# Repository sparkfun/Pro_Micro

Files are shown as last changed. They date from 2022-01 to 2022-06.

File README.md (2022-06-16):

SparkFun Pro Micro and Qwiic Pro Micro USB-C
========================================

<table class="table table-hover table-striped table-bordered">
  <tr>
   <td><a href="https://www.sparkfun.com/products/12587"><div align="center">Pro Micro - 3.3V/8MHz</div></a></td>
   <td><a href="https://www.sparkfun.com/products/12640">Pro Micro - 5V/16MHz</div></a></center></td>
  </tr>
  <tr>
    <td><div align="center">Pro Micro - 3.3V/8MHz <br />[<a href="https://www.sparkfun.com/products/12587">DEV-12587</a>]</div></td>
    <td><div align="center">Pro Micro - 5V/16MHz <br />[<a href="https://www.sparkfun.com/products/12640">DEV-12640</a>]</div></td>
    <td><div align="center">Qwiic Pro Micro - USB-C (ATmega32U4) <br />[<a href="https://www.sparkfun.com/products/15795">DEV-15795</a>]</div></td>
  </tr>
</table>

The Pro Micro is a microcontroller with an ATMega32U4 IC on board. The USB transceiver is inside the 32U4, adding USB connectivity on-board without external USB interfaces. The Pro Micro comes in both a 3.3V and 5V version. For users using the Qwiic Pro Micro USB-C, the board includes a jumper to select either 5V or 3.3V, reset button, castellated pads, and Qwiic connector. The USB connector and voltage regulator are also different. 

Repository Contents
-------------------
* **/Documentation** - Data sheets (.pdf and .svg)
* **/Firmware** - Arduino example code used in the hookup guide
* **/Hardware** - All Eagle design files (.brd, .sch, .STL)
* **/Production** - Test bed files and production panel files

Documentation
--------------
* **Hookup Guide** 
  * **[Pro Micro & Fio V3](https://learn.sparkfun.com/tutorials/pro-micro--fio-v3-hookup-guide)** - Basic hookup guide for the Pro Micro (ATmega32U4) 3.3V and 5V versions as well as the Fio V3.
  * **[Qwiic Pro Micro USB-C](https://learn.sparkfun.com/tutorials/qwiic-pro-micro-usb-c-atmega32u4-hookup-guide)** - Basic hookup guide for the Qwiic Pro Micro.
* **[SparkFun Arduino Board Addon](https://github.com/sparkfun/Arduino_Boards/)** - Arduino board addon for Qwiic Pro Micro.
* **[SparkFun Graphical Datasheets](https://github.com/sparkfun/Graphical_Datasheets)** - Graphical datasheets for various SparkFun products.
* **[SparkFun Fritzing repo](https://github.com/sparkfun/Fritzing_Parts)** - Fritzing diagrams for SparkFun products.

Product Versions
----------------
* [DEV-15795](https://www.sparkfun.com/products/15795)- 5V/16MHz version with Qwiic connector and USB C
* [DEV-12640](https://www.sparkfun.com/products/12640)- 5V/16MHz version
* [DEV-12587](https://www.sparkfun.com/products/12587)- 3.3V/8MHz version

License Information
-------------------
This product is _**open source**_! 

Please review the LICENSE.md file for license information. 

If you have any questions or concerns on licensing, please contact technical support on our [SparkFun forums](https://forum.sparkfun.com/viewforum.php?f=152).

Distributed as-is; no warranty is given.

- Your friends at SparkFun.

_<COLLABORATION CREDIT>_

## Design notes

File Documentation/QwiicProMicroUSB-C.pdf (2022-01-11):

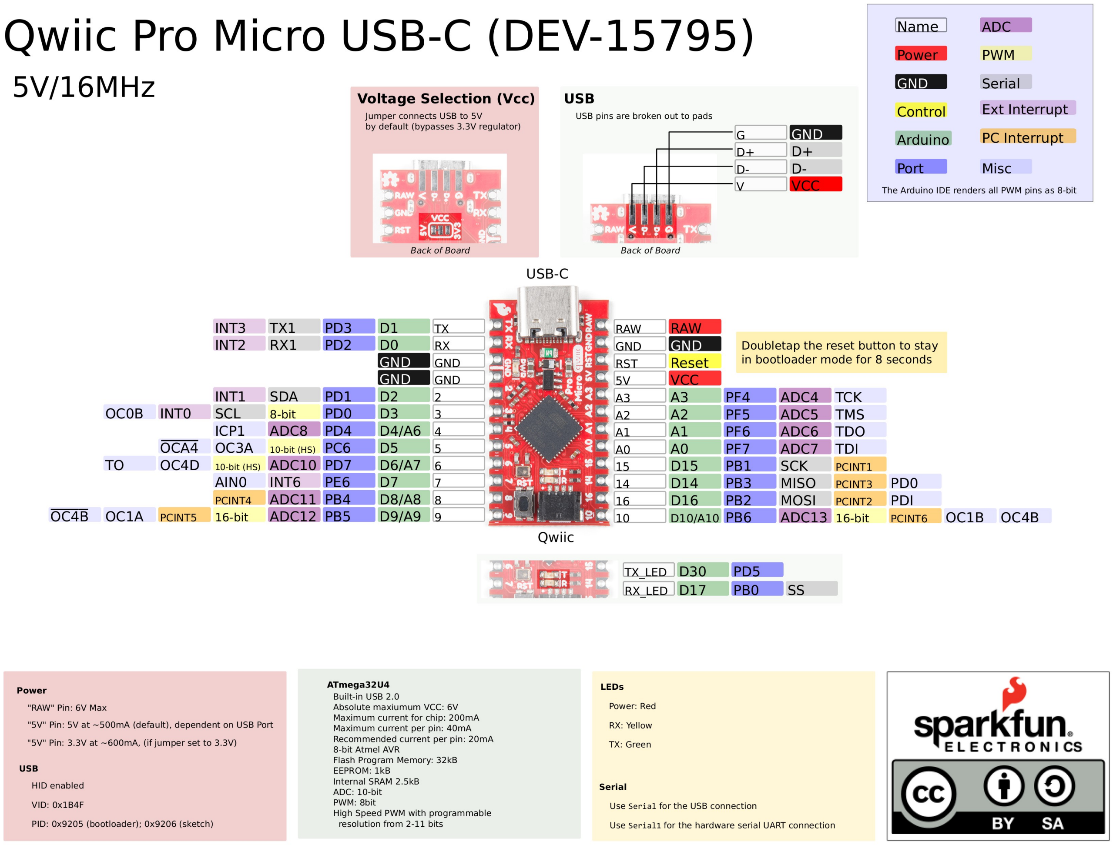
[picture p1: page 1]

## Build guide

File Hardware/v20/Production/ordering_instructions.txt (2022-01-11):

panel size, 133x196mm
PCB thickness, 1.6mm
number of layers, 2
soldermask color, Red
silkscreen color, White
oz copper, 1oz
finish, HASL lead free
stencils, top
pcs per panel, 20
min trace width, 0.152400mm / 0.006000in
min drill size, 0.304800mm / 0.012000in

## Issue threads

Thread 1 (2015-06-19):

Pro Micro v 1.3 schematic has Arduino IDE pin 14 and 17 labels swapped

dmjlambert, 2015-06-19:
Arduino Pin 14 is 32U4 pin 11/MISO and Arduino Pin 17 is 32U4 pin 8/SS which is connected to the RXLED

BrentWilkins, 2015-06-19:
Fixed.  We were using an old version of the ATmega32U4 part.  Thanks!

dmjlambert, 2015-06-20:
I'm sorry Brent, I was not clear and I should have given you more details.   I'm afraid the changes you made were not what I was talking about, could you please revert it back and make different changes?
 Could you please have a look at this attached picture?
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

BrentWilkins, 2015-06-20:
No, you were plenty clear to me.  I fixed it in the v13.1_3.3V branch.  I did so by using current library parts which caused copper to be negligibly altered.  Can't release that until it's proto'd since it's a hot product.  Not sure why the main branch is still wrong.  Feel free to use the v13.1 (3.3V) branch as a reference.

Closed 2015-06-19.

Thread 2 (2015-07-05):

SS & MISO swapped on 32U4

uChip, 2015-07-05:
From the Pro Micro schematic it appears that SS & MISO pins are swapped on the ATMEGA32U4 ucontroller component in the Testing library.  According to the Atmel data sheet pin 8 should be PB0(SS) and pin 11 should be PB3(MISO).  Note this appears to be an issue with library component pin names only.  Schematic signal names and use appear to be correct.

This has caused a couple of questions in the forum: https://forum.sparkfun.com/viewtopic.php?f=14&t=41432

Thanks,
Chip

BrentWilkins, 2015-07-05:
Correct.  This is a know, kind of fixed, issue.  Please refer to issue #1.  Look at this branch: https://github.com/sparkfun/Pro_Micro/tree/v13.1_3.3V for a corrected version.

Closed 2015-07-05.

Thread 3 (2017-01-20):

OC4x Pins are incorrectly marked on the Graphical Datasheet

dn3s, 2017-01-20:
The datasheet correctly lists `OC4D` as on `PD7` (pin 6 on the Pro Micro), but it gets the pins for `OC3A` and `OC3B` wrong:

- `OC4A` is on `PC7` (not broken out on the Pro Micro), not pin 5 as listed in the datasheet (which in reality has `OC4A`'s complementary output).
- `OC4B` is on `PB6` (pin 10 on the Pro Micro), not pin 9 as listed in the datasheet (which in reality has `OC4B`'s complementary output).

(This can all be verified in section 10.3 (page 70) of the [ATmega16/32U4 Full Datasheet](http://www.atmel.com/Images/Atmel-7766-8-bit-AVR-ATmega16U4-32U4_Datasheet.pdf))

I discovered this issue while creating a library to generate high-speed PWM (up to 250kHz!) using the 32u4's cool ability to clock TC4 from the chip's bilt-in PLL. So in addition to creating a headache troubleshooting PWM hacking code, it also is misleading for potential buyers in that it looks like all 3 of TC4's Output Compare units are broken out when in fact only 2 are directly (aside from through complimentary ouputs which are kinda a hackish solution)

Anyways, all this to say, pls fix this in the graphical datasheet!

_As an aside, given that high-speed PWM is one of (IMO) the top 5 coolest features of the ATmega32u4, it would be cool if you someday released a tiny Atmega32u4-based board that broke out all 6 outputs (all 3 regular and inverted) for the TC4-based PWMs. This would enable all sorts of cool applications, like directly controlling FETs for a homebrew RGB LED sync buck driver, or homebrew 3-phase BLDC drivers, a kinda hackish 3-output SMPS, and many more possibilities! My own project only needs 2 HSPWMs, so I got lucky, but I think a microcontroller board with 3 high-speed PWMs, inverted outputs, and dead-time generation could be a big selling feature!_

mshorter, 2017-01-27:
All fixed, thanks for the feedback.

dn3s, 2017-01-28:
thanks for fixing, looks much better now!
Sorry to be picky, but would you be able to push the changed files to github as well? i like grabbing info like this from the source and I feel like I'll probably forget in the future to download them from the website

ToniCorinne, 2017-01-31:
@dn3s  they have been pushed to the repo. Thanks for your patience!

dn3s, 2017-02-02:
thanks!

Closed 2017-01-27.

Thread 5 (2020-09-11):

Export of dimensions from eagle files

joesphan, 2020-09-11:
Hello! I do not have eagle, could someone grab the dimensions for me?
thanks in advance

bboyho, 2020-09-11:
Hi,

The dimensions are listed on the respective product pages under the Features tab. However, I have added the board dimensions to the product page and hookup guide for future reference.

The Pro Micro is **1.30"x0.70"**. Note that the USB connector adds a small bit of length to the board so the total length is about **1.37"**. Enjoy. =)

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

Closed 2020-09-11.

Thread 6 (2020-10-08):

SPARKFUN_PRO_MICRO pin assignment is wrong

c-toyama, 2020-10-08:
Pin 14: 11-> 16
Pin 15: 12-> 14
Pin 16: 13-> 15

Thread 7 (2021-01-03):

USB-C Connector Source

Gigahawk, 2021-01-03:
What's the source for the USB-C connector?
There doesn't seem to be a library available with the package being used.
I'm looking to get the 3D model for it.

nseidle, 2021-01-05:
[Datasheet](https://cdn.sparkfun.com/assets/8/6/b/4/5/A40-00119-A52-12.pdf) from [connector page](https://www.sparkfun.com/products/15111) should get you what you need.

Closed 2021-01-05.

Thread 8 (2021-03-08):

Pin out D+/D-?

myst729, 2021-03-08:
Is it possible to pin out D+/D-? Want to connect pro micro to a USB Type-C breakout board.

ardasysmic, 2021-03-08:
[USB4110-GF-A.zip](https://github.com/sparkfun/Pro_Micro/files/6101126/USB4110-GF-A.zip)

Yes, is same. For example with this library for Eagle

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

myst729, 2021-03-09:
@ardasysmic Yes, I know what you mean. Currently I take off the micro-usb connector on Pro Micro, and fly lines to the type-c breakout board. I'm requesting to pin out the D+/D- like normal GPIOs. Something like this:

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

nseidle, 2021-03-09:
A good idea that has been implemented on the newer [Pro Micro C](https://www.sparkfun.com/products/15795):

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

We don't have plans to update the microB version of this board so I'm closing out issue.

Closed 2021-03-09.

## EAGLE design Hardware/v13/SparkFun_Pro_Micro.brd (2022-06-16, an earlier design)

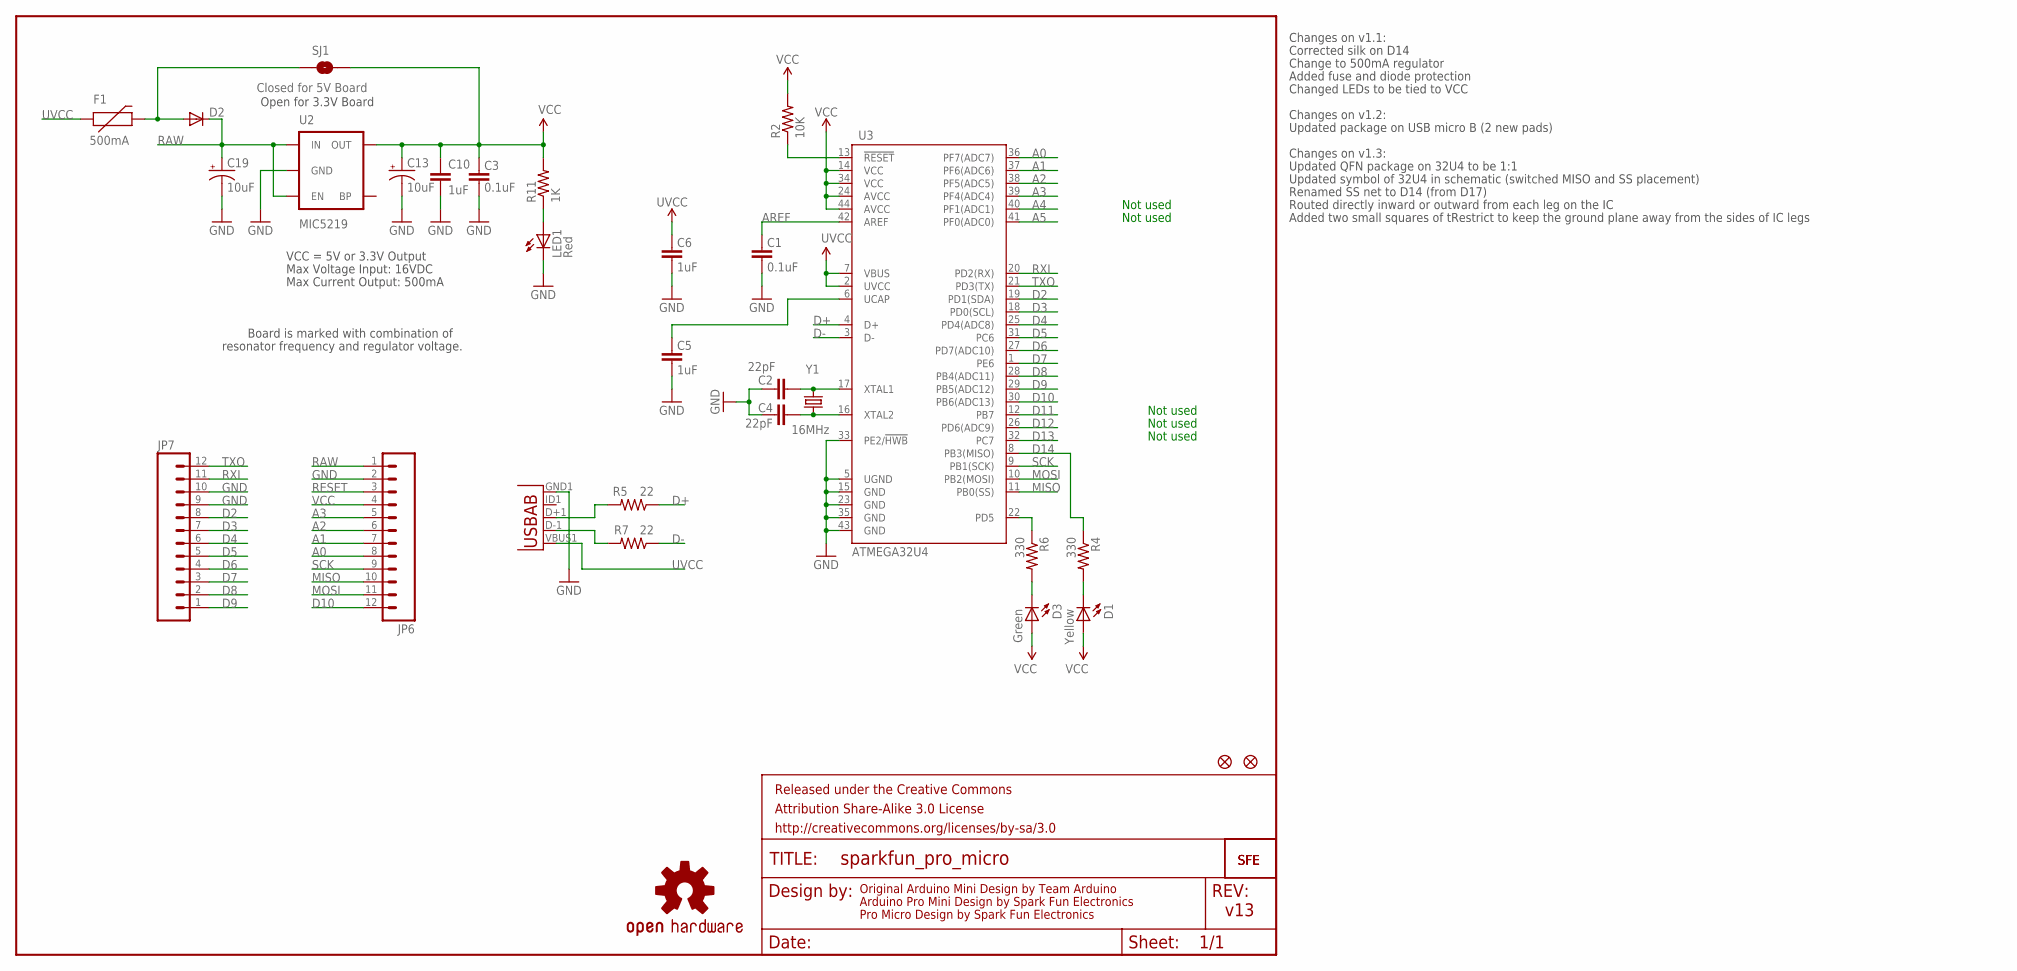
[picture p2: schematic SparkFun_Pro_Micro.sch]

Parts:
C1, C3: 0.1uF; 0603-CAP
C2, C4: 22pF; 0603-CAP
C5, C6, C10: 1uF; 0603-CAP
C13, C19: 10uF; EIA3216
D1: Yellow; LED-0603
D2: DIODESOD; SOD-323
D3: Green; LED-0603
F1: 500mA; PTC-1206
FRAME1: FRAME-LETTER; CREATIVE_COMMONS
JP1, JP2: FIDUCIALUFIDUCIAL; MICRO-FIDUCIAL
JP6, JP7: M12PTH; 1X12
LED1: Red; LED-0603
R2: 10K; 0603-RES
R4, R6: 330; 0603-RES
R5, R7: 22; 0603-RES
R11: 1K; 0603-RES
SJ1: Closed for 5V Board; SJ_2S
U2: MIC5219; SOT23-5
U3: ATMEGA32U4; QFN-44-NOPAD_1:1-OUTFAKES
U$1: LOGO-SFESK; SFE-LOGO-FLAME
U$3: OSHW-LOGOS; OSHW-LOGO-S
U$11: LOGO-SFENEW; SFE-NEW-WEBLOGO
X1: USB-ABIN&OUT; USB-AB-MICRO-SMD-V03-IN&OUT
Y1: 16MHz; CRYSTAL-SMD-5X3

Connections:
A0: JP6.8, U3.36 (PF7(ADC7))
A1: JP6.7, U3.37 (PF6(ADC6))
A2: JP6.6, U3.38 (PF5(ADC5))
A3: JP6.5, U3.39 (PF4(ADC4))
A4: U3.40 (PF1(ADC1))
A5: U3.41 (PF0(ADC0))
AREF: C1.2, U3.42 (AREF)
D2: JP7.8, U3.19 (PD1(SDA))
D3: JP7.7, U3.18 (PD0(SCL))
D4: JP7.6, U3.25 (PD4(ADC8))
D5: JP7.5, U3.31 (PC6)
D6: JP7.4, U3.27 (PD7(ADC10))
D7: JP7.3, U3.1 (PE6)
D8: JP7.2, U3.28 (PB4(ADC11))
D9: JP7.1, U3.29 (PB5(ADC12))
D10: JP6.12, U3.30 (PB6(ADC13))
D11: U3.12 (PB7)
D12: U3.26 (PD6(ADC9))
D13: U3.32 (PC7)
D14: R4.1, U3.8 (PB3(MISO))
D+: R5.1, U3.4 (D+)
D-: R7.1, U3.3 (D-)
GND: C1.1, C2.2, C3.1, C4.2, C5.1, C6.1, C10.2, C13.C (-), C19.C (-), JP6.2, JP7.9, JP7.10, LED1.C, U2.2 (GND), U3.5 (UGND), U3.15 (GND), U3.23 (GND), U3.33 (PE2/!HWB), U3.35 (GND), U3.43 (GND), X1.GND1 (GND)
MISO: JP6.10, U3.11 (PB0(SS))
MOSI: JP6.11, U3.10 (PB2(MOSI))
unnamed: C4.1, U3.16 (XTAL2), Y1.1
unnamed: C2.1, U3.17 (XTAL1), Y1.3 (2)
unnamed: D2.2 (A), F1.2, SJ1.1
unnamed: C5.2, U3.6 (UCAP)
unnamed: D1.C, R4.2
unnamed: R7.2, X1.D-1 (D-)
unnamed: D3.C, R6.2
unnamed: R5.2, X1.D+1 (D+)
unnamed: LED1.A, R11.1
RAW: C19.A (+), D2.1 (C), JP6.1, U2.1 (IN), U2.3 (EN)
RESET: JP6.3, R2.1, U3.13 (!RESET)
RXI: JP7.11, U3.20 (PD2(RX))
SCK: JP6.9, U3.9 (PB1(SCK))
TXLED: R6.1, U3.22 (PD5)
TXO: JP7.12, U3.21 (PD3(TX))
UVCC: C6.2, F1.1, U3.2 (UVCC), U3.7 (VBUS), X1.VBUS1 (VBUS)
VCC: C3.2, C10.1, C13.A (+), D1.A, D3.A, JP6.4, R2.2, R11.2, SJ1.2, U2.5 (OUT), U3.14 (VCC), U3.24 (AVCC), U3.34 (VCC), U3.44 (AVCC)

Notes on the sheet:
Original Arduino Mini Design by Team Arduino
Arduino Pro Mini Design by Spark Fun Electronics
Max Voltage Input: 16VDC
Max Current Output: 500mA
Board is marked with combination of
resonator frequency and regulator voltage.
VCC = 5V or 3.3V Output
Not used
Pro Micro Design by Spark Fun Electronics
Changes on v1.1:
Corrected silk on D14
Change to 500mA regulator
Open for 3.3V Board
Added fuse and diode protection
Changed LEDs to be tied to VCC
Changes on v1.2:
Updated package on USB micro B (2 new pads)
Changes on v1.3:
Updated QFN package on 32U4 to be 1:1
Updated symbol of 32U4 in schematic (switched MISO and SS placement)
Renamed SS net to D14 (from D17)
Routed directly inward or outward from each leg on the IC
Added two small squares of tRestrict to keep the ground plane away from the sides of IC legs
v13

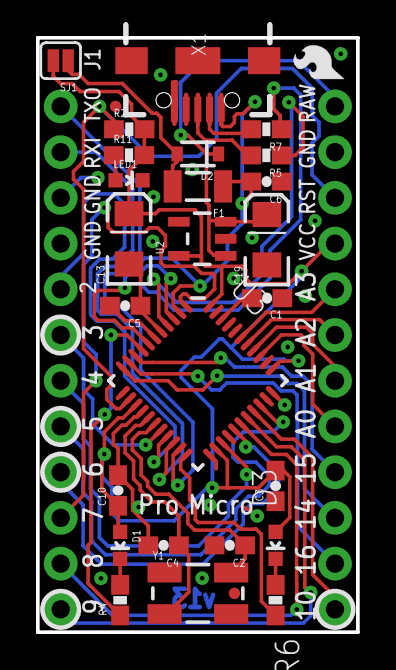
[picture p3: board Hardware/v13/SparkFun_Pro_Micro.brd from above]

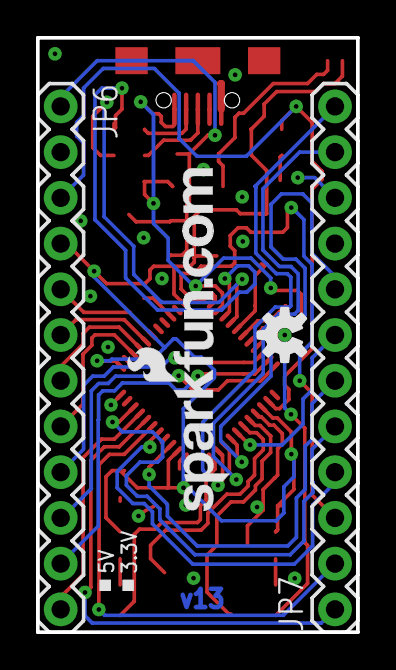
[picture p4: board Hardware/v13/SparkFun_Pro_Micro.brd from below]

Board: 2 copper layers, 17.8 x 33.0 mm, 33 parts (4 on the bottom side), 37 nets.

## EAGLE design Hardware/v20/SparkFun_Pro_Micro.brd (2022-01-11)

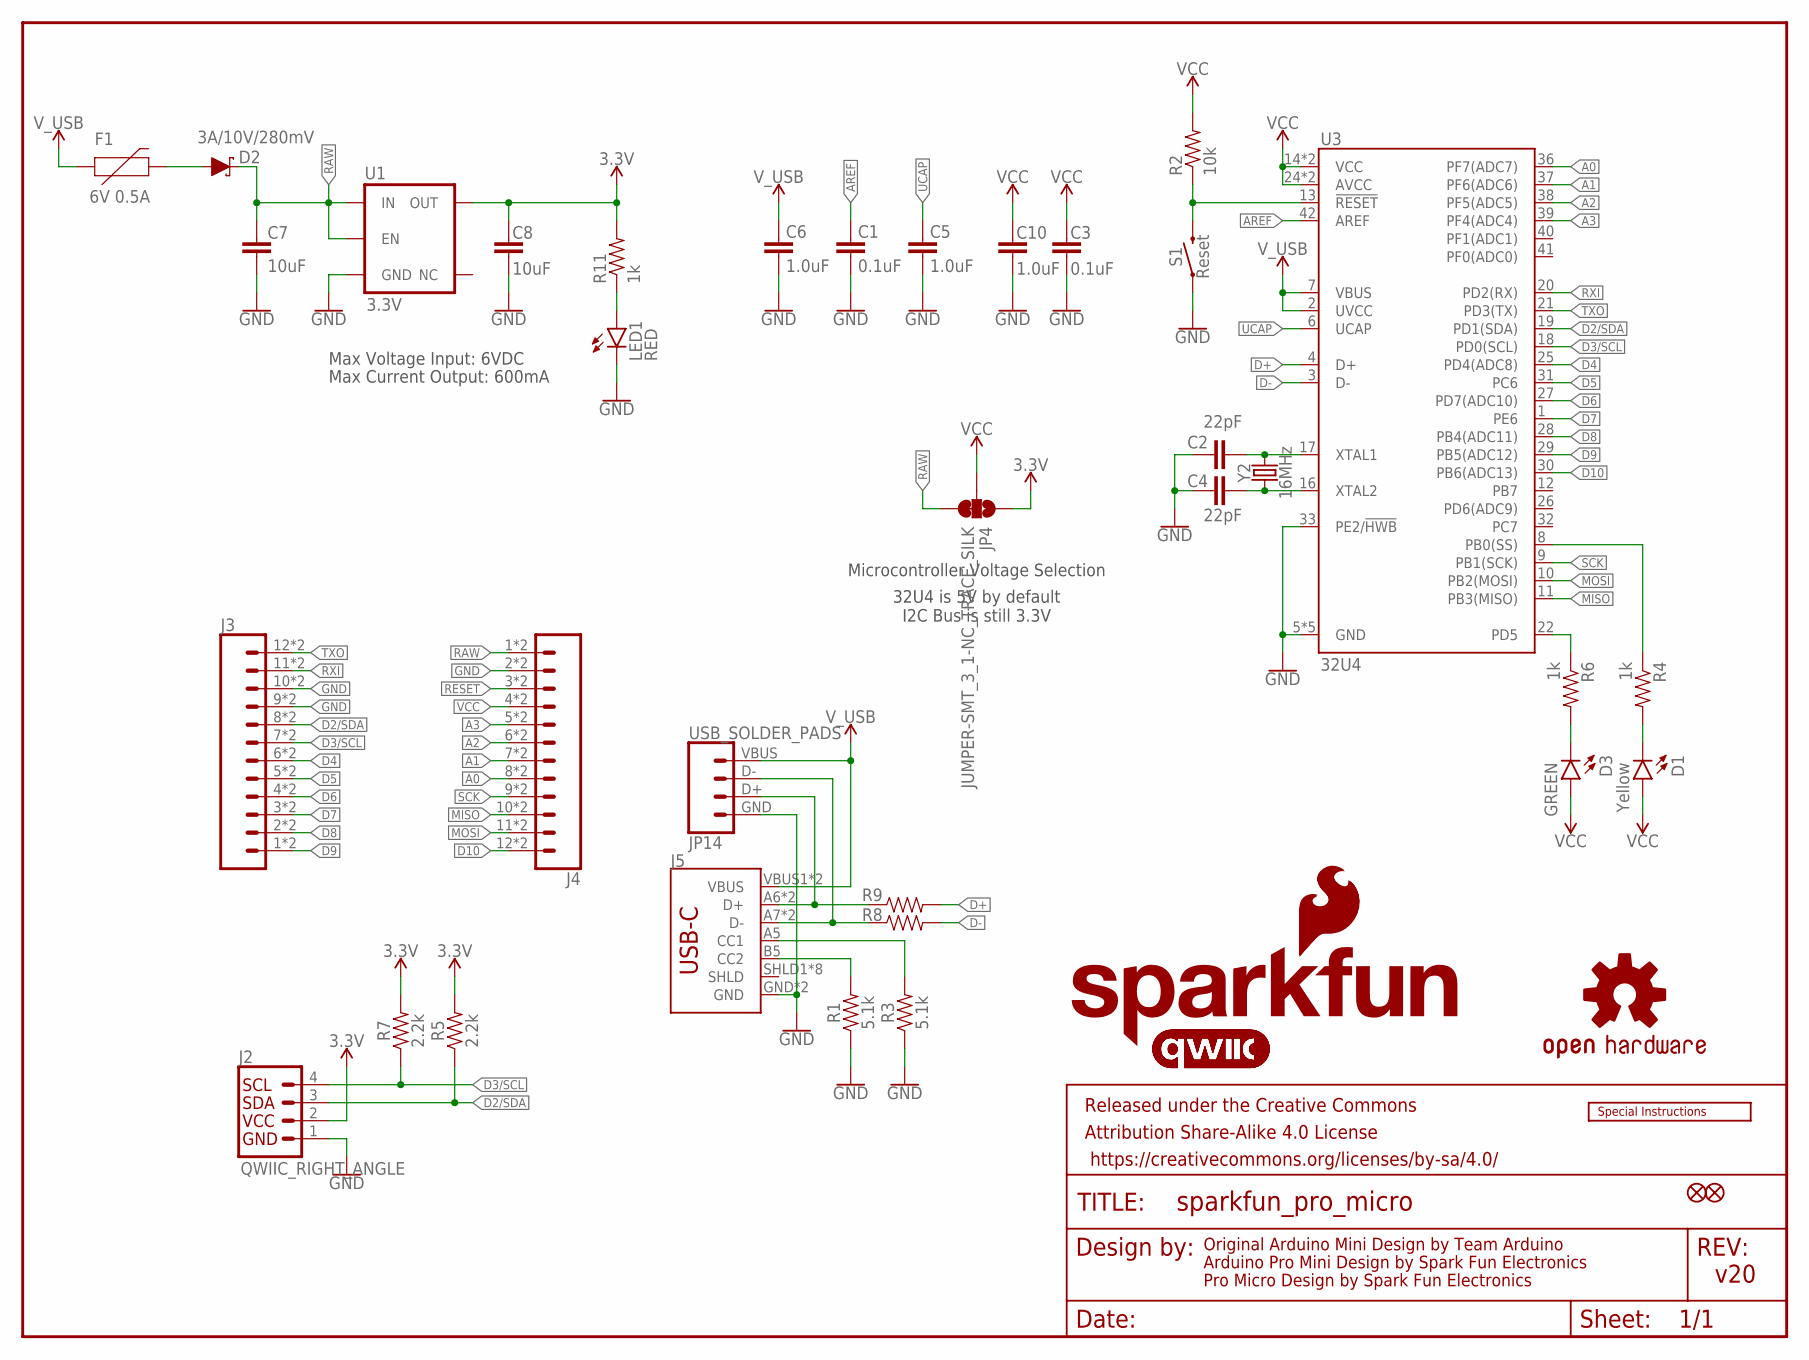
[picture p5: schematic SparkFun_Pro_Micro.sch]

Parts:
C1, C3: 0.1uF; 0402-TIGHT
C2, C4: 22pF; 0402-TIGHT
C5, C6, C10: 1.0uF; 0402-TIGHT
C7, C8: 10uF; 0603
D1: Yellow; LED-0603
D2: 3A/10V/280mV; SOD-323
D3: GREEN; LED-0603
F1: 6V 0.5A; 0805
FRAME1: FRAME-LETTER; CREATIVE_COMMONS
J2: QWIIC_RIGHT_ANGLE; JST04_1MM_RA
J3, J4: CONN_12CASTLE; 1X12_CASTELLATED
J5: USB_C5; USB-C-16P-5
JP1, JP2: FIDUCIAL1X2; FIDUCIAL-1X2
JP4: JUMPER-SMT_3_1-NC_TRACE_SILK; SMT-JUMPER_3_1-NC_TRACE_SILK
JP14: USB_SOLDER_PADS; USB-SOLDER-PADS
LED1: RED; LED-0603
LOGO1: SFE_LOGO_NAME_FLAME.1_INCH; SFE_LOGO_NAME_FLAME_.1
LOGO2: QWIIC_LOGO_4MM; QWIIC_4MM
LOGO3: QWIIC_LOGO_6MM; QWIIC_6MM
LOGO4: SFE_LOGO_FLAME.1_INCH; SFE_LOGO_FLAME_.1
LOGO5: SPECIAL_INSTRUCTIONS-ORDERING; ORDERING_INSTRUCTIONS
R1, R3: 5.1k; 0402-TIGHT
R2: 10k; 0402-TIGHT
R4, R6, R11: 1k; 0402-TIGHT
R5, R7: 2.2k; 0402-TIGHT
R8, R9: 22OHM-0402T-1/16W-1%; 0402-TIGHT
S1: Reset; TACTILE_SWITCH_SMD_4.6X2.8MM
U1: 3.3V; SOT23-5
U3: 32U4; QFN-44-NOPAD_1:1-LESS_PASTE
U$3: OSHW-LOGOMINI; OSHW-LOGO-MINI
Y2: 16MHz; CRYSTAL-SMD-2.0X1.6MM

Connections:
3.3V: C8.2, J2.2, JP4.1, R5.2, R7.2, R11.2, U1.5 (OUT)
A0: J4.8, J4.8B (8), U3.36 (PF7(ADC7))
A1: J4.7, J4.7B (7), U3.37 (PF6(ADC6))
A2: J4.6, J4.6B (6), U3.38 (PF5(ADC5))
A3: J4.5, J4.5B (5), U3.39 (PF4(ADC4))
AREF: C1.2, U3.42 (AREF)
D2/SDA: J2.3, J3.8, J3.8B (8), R5.1, U3.19 (PD1(SDA))
D3/SCL: J2.4, J3.7, J3.7B (7), R7.1, U3.18 (PD0(SCL))
D4: J3.6, J3.6B (6), U3.25 (PD4(ADC8))
D5: J3.5, J3.5B (5), U3.31 (PC6)
D6: J3.4, J3.4B (4), U3.27 (PD7(ADC10))
D7: J3.3, J3.3B (3), U3.1 (PE6)
D8: J3.2, J3.2B (2), U3.28 (PB4(ADC11))
D9: J3.1, J3.1B (1), U3.29 (PB5(ADC12))
D10: J4.12, J4.12B (12), U3.30 (PB6(ADC13))
D+: R9.2, U3.4 (D+)
D-: R8.2, U3.3 (D-)
D-_HV: J5.A7 (D-), J5.B7 (D-), JP14.D- (2), R8.1
DP_HV: J5.A6 (D+), J5.B6 (D+), JP14.D+ (3), R9.1
GND: C1.1, C2.2, C3.1, C4.2, C5.1, C6.1, C7.1, C8.1, C10.1, J2.1, J3.9, J3.9B (9), J3.10, J3.10B (10), J4.2, J4.2B (2), J5.GND, J5.GND2 (GND), JP14.GND (4), LED1.C, R1.1, R3.1, S1.1, S1.2 (1), U1.2 (GND), U3.5 (GND), U3.15 (GND), U3.23 (GND), U3.33 (PE2/!HWB), U3.35 (GND), U3.43 (GND)
MISO: J4.10, J4.10B (10), U3.11 (PB3(MISO))
MOSI: J4.11, J4.11B (11), U3.10 (PB2(MOSI))
unnamed: C4.1, U3.16 (XTAL2), Y2.1
unnamed: C2.1, U3.17 (XTAL1), Y2.3 (2)
unnamed: D1.C, R4.2
unnamed: D3.C, R6.2
unnamed: J5.A5 (CC1), R3.2
unnamed: J5.B5 (CC2), R1.2
unnamed: LED1.A, R11.1
RAW: C7.2, D2.C, J4.1, J4.1B (1), JP4.3, U1.1 (IN), U1.3 (EN)
RESET: J4.3, J4.3B (3), R2.1, S1.3 (2), S1.4 (2), U3.13 (!RESET)
RXI: J3.11, J3.11B (11), U3.20 (PD2(RX))
RXLED: R4.1, U3.8 (PB0(SS))
SCK: J4.9, J4.9B (9), U3.9 (PB1(SCK))
TXLED: R6.1, U3.22 (PD5)
TXO: J3.12, J3.12B (12), U3.21 (PD3(TX))
UCAP: C5.2, U3.6 (UCAP)
USB_RAW: D2.A, F1.2
VCC: C3.2, C10.2, D1.A, D3.A, J4.4, J4.4B (4), JP4.2, R2.2, U3.14 (VCC), U3.24 (AVCC), U3.34 (VCC), U3.44 (AVCC)
V_USB: C6.2, F1.1, J5.VBUS1 (VBUS), J5.VBUS2 (VBUS), JP14.VBUS (1), U3.2 (UVCC), U3.7 (VBUS)

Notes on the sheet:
Original Arduino Mini Design by Team Arduino
Arduino Pro Mini Design by Spark Fun Electronics
Max Voltage Input: 6VDC
Max Current Output: 600mA
Pro Micro Design by Spark Fun Electronics
Microcontroller Voltage Selection
v20
32U4 is 5V by default I2C Bus is still 3.3V

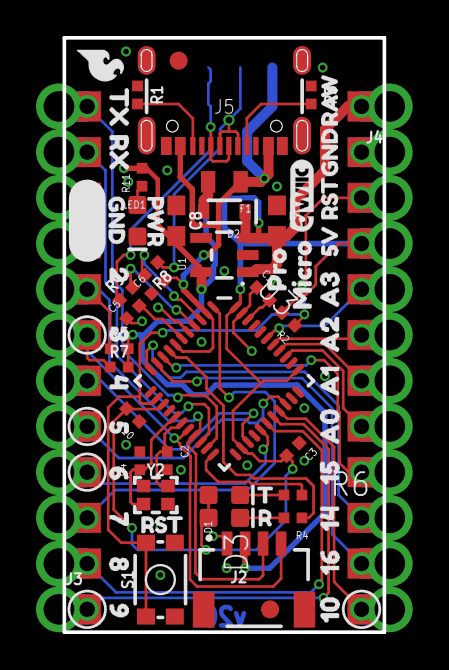
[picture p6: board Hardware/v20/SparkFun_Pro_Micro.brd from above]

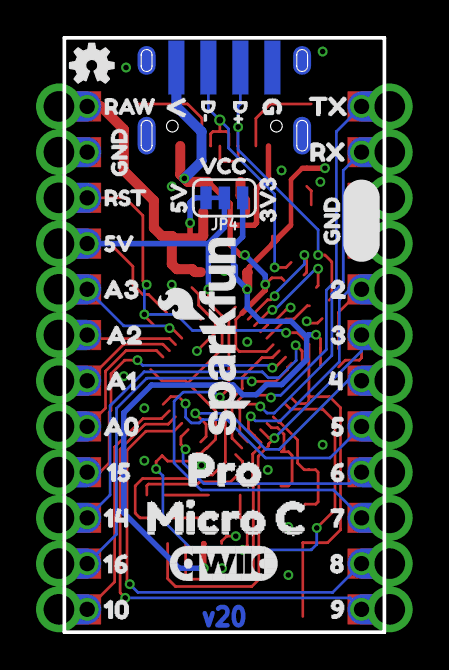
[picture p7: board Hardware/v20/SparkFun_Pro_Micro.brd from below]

Board: 2 copper layers, 17.8 x 33.0 mm, 105 parts (38 on the bottom side), 40 nets.

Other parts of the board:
U$1: VCC1
U$2, U$38: 156
U$4, U$48: 164
U$5, U$57: 218
U$6, U$56: 317
U$7, U$54: 515
U$8, U$53: 614
U$9, U$52: 713
U$10, U$51: 812
U$11, U$22, U$32, U$58: GND4
U$12, U$46: RAW5
U$13, U$55: 45
U$14: T8
U$15, U$64, U$65: 5V1
U$16, U$50: 911
U$17, U$37: A07
U$18, U$60: TX2
U$19, U$36: A18
U$21, U$49: 104
U$23: MICRO1
U$24: PRO0
U$25, U$31, U$41: RST3
U$26, U$35: A29
U$27, U$34: A310
U$28, U$59: RX20
U$29, U$47: 145
U$30: R9
U$39: 3V39
U$40: C5
U$42: G1
U$43: MICRO4
U$44: V0
U$45: PRO3
U$61: D#3
U$62: D#4
U$63: PWR0

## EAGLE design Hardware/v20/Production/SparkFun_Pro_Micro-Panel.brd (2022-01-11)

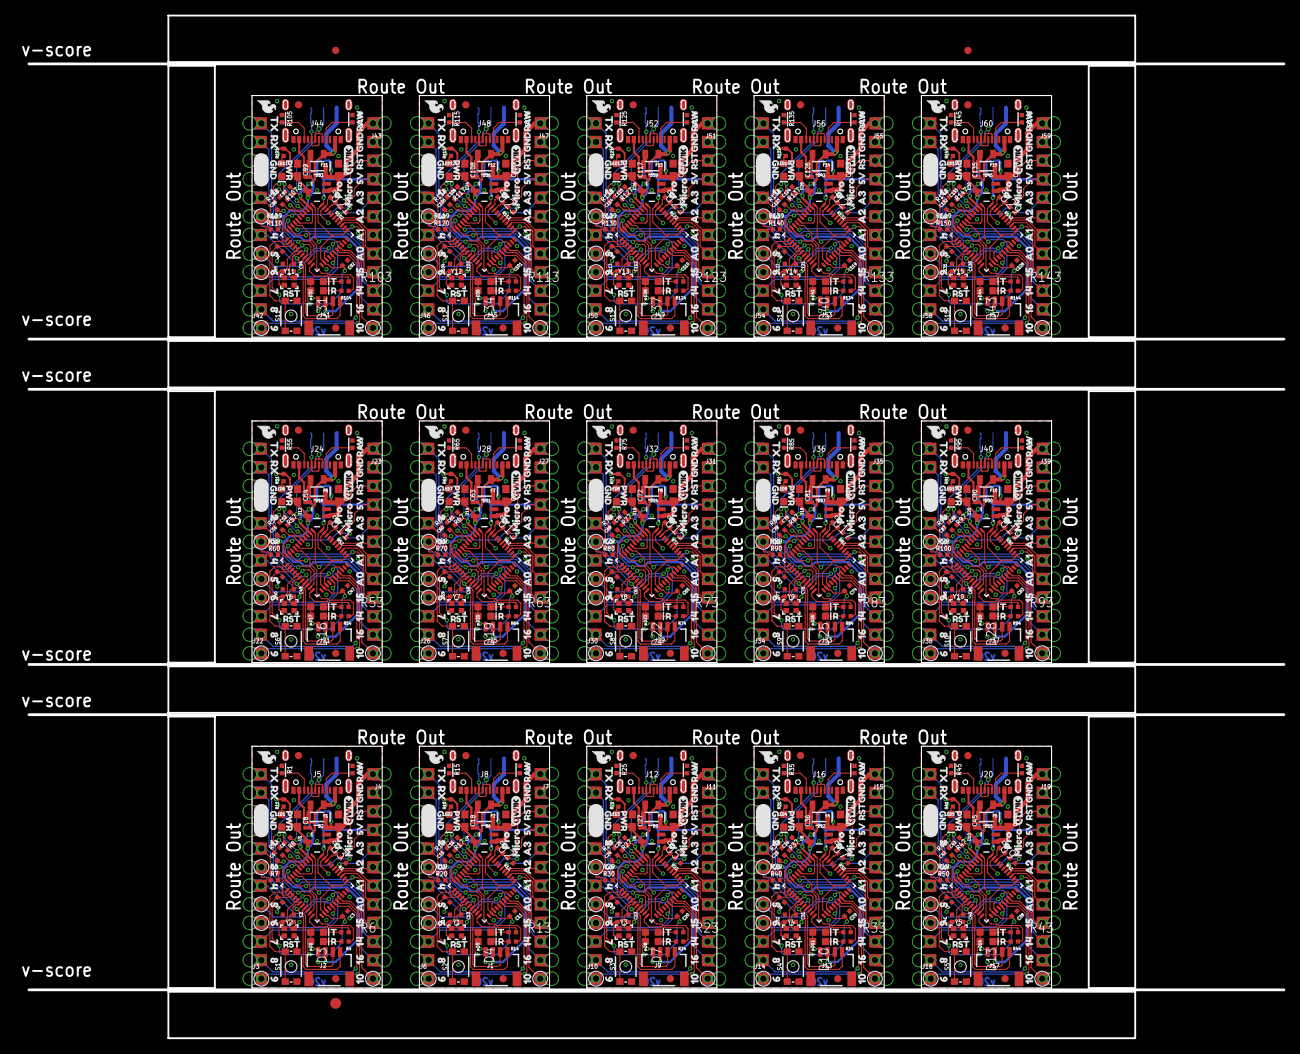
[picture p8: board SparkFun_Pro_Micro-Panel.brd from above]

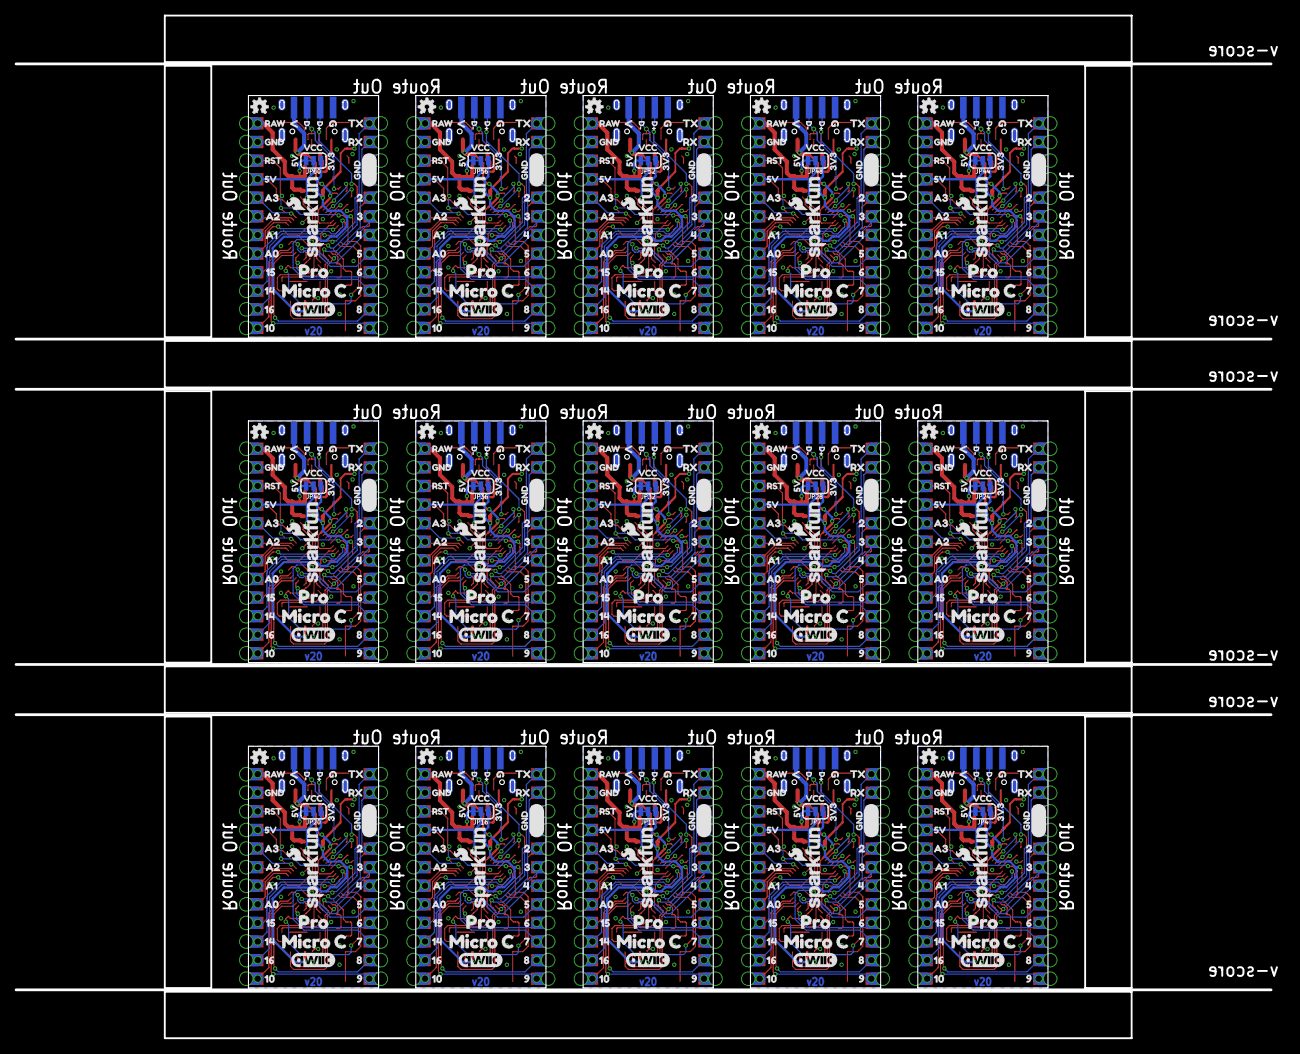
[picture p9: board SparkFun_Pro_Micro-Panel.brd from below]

Board: 2 copper layers, 171.4 x 139.7 mm, 1548 parts (570 on the bottom side), 600 nets.

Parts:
C1, C3, C11, C12, C20, C21, C29, C30, C38, C39, C47, C48, C56, C57, C65, C66, C74, C75, C83, C84, C92, C93, C101, C102, C110, C111, C119, C120, C128, C129: 0.1uF; 0402-TIGHT
C2, C4, C13, C14, C22, C23, C31, C32, C40, C41, C49, C50, C58, C59, C67, C68, C76, C77, C85, C86, C94, C95, C103, C104, C112, C113, C121, C122, C130, C131: 22pF; 0402-TIGHT
C5, C6, C9, C10, C15, C16, C19, C24, C25, C28, C33, C34, C37, C42, C43, C46, C51, C52, C55, C60, C61, C64, C69, C70, C73, C78, C79, C82, C87, C88, C91, C96, C97, C100, C105, C106, C109, C114, C115, C118, C123, C124, C127, C132, C133: 1.0uF; 0402-TIGHT
C7, C8, C17, C18, C26, C27, C35, C36, C44, C45, C53, C54, C62, C63, C71, C72, C80, C81, C89, C90, C98, C99, C107, C108, C116, C117, C125, C126, C134, C135: 10uF; 0603
D1, D5, D8, D11, D14, D17, D20, D23, D26, D29, D32, D35, D38, D41, D44: Yellow; LED-0603
D2, D6, D9, D12, D15, D18, D21, D24, D27, D30, D33, D36, D39, D42, D45: 3A/10V/280mV; SOD-323
D3, D4, D7, D10, D13, D16, D19, D22, D25, D28, D31, D34, D37, D40, D43: GREEN; LED-0603
E$1, E$2: FIDUCIAL-1X2
E$3: FIDUCIAL-1.5X3
F1, F2, F3, F4, F5, F6, F7, F8, F9, F10, F11, F12, F13, F14, F15: 6V 0.5A; 0805
J1, J2, J9, J13, J17, J21, J25, J29, J33, J37, J41, J45, J49, J53, J57: Qwiic; JST04_1MM_RA
J3, J4, J6, J7, J10, J11, J14, J15, J18, J19, J22, J23, J26, J27, J30, J31, J34, J35, J38, J39, J42, J43, J46, J47, J50, J51, J54, J55, J58, J59: 1X12_CASTELLATED
J5, J8, J12, J16, J20, J24, J28, J32, J36, J40, J44, J48, J52, J56, J60: USB-C-16P-5
JP1, JP2, JP3, JP5, JP8, JP9, JP12, JP13, JP17, JP18, JP21, JP22, JP25, JP26, JP29, JP30, JP33, JP34, JP37, JP38, JP41, JP42, JP45, JP46, JP49, JP50, JP53, JP54, JP57, JP58: FIDUCIAL1X2; FIDUCIAL-1X2
JP4, JP7, JP11, JP16, JP20, JP24, JP28, JP32, JP36, JP40, JP44, JP48, JP52, JP56, JP60: SMT-JUMPER_3_1-NC_TRACE_SILK
JP6, JP10, JP14, JP15, JP19, JP23, JP27, JP31, JP35, JP39, JP43, JP47, JP51, JP55, JP59: USB_SOLDER_PADS; USB-SOLDER-PADS
LED1, LED2, LED3, LED4, LED5, LED6, LED7, LED8, LED9, LED10, LED11, LED12, LED13, LED14, LED15: RED; LED-0603
LOGO1, LOGO5, LOGO9, LOGO13, LOGO17, LOGO21, LOGO25, LOGO29, LOGO33, LOGO37, LOGO41, LOGO45, LOGO49, LOGO53, LOGO57: SFE_LOGO_NAME_FLAME.1_INCH; SFE_LOGO_NAME_FLAME_.1
LOGO2, LOGO6, LOGO10, LOGO14, LOGO18, LOGO22, LOGO26, LOGO30, LOGO34, LOGO38, LOGO42, LOGO46, LOGO50, LOGO54, LOGO58: QWIIC_LOGO_4MM; QWIIC_4MM
LOGO3, LOGO7, LOGO11, LOGO15, LOGO19, LOGO23, LOGO27, LOGO31, LOGO35, LOGO39, LOGO43, LOGO47, LOGO51, LOGO55, LOGO59: QWIIC_LOGO_6MM; QWIIC_6MM
LOGO4, LOGO8, LOGO12, LOGO16, LOGO20, LOGO24, LOGO28, LOGO32, LOGO36, LOGO40, LOGO44, LOGO48, LOGO52, LOGO56, LOGO60: SFE_LOGO_FLAME.1_INCH; SFE_LOGO_FLAME_.1
R1, R3, R15, R16, R25, R26, R35, R36, R45, R46, R55, R56, R65, R66, R75, R76, R85, R86, R95, R96, R105, R106, R115, R116, R125, R126, R135, R136, R145, R146: 5.1k; 0402-TIGHT
R2, R12, R22, R32, R42, R52, R62, R72, R82, R92, R102, R112, R122, R132, R142: 10k; 0402-TIGHT
R4, R6, R10, R11, R13, R14, R21, R23, R24, R31, R33, R34, R41, R43, R44, R51, R53, R54, R61, R63, R64, R71, R73, R74, R81, R83, R84, R91, R93, R94, R101, R103, R104, R111, R113, R114, R121, R123, R124, R131, R133, R134, R141, R143, R144: 1k; 0402-TIGHT
R5, R7, R19, R20, R29, R30, R39, R40, R49, R50, R59, R60, R69, R70, R79, R80, R89, R90, R99, R100, R109, R110, R119, R120, R129, R130, R139, R140, R149, R150: 2.2k; 0402-TIGHT
R8, R9, R17, R18, R27, R28, R37, R38, R47, R48, R57, R58, R67, R68, R77, R78, R87, R88, R97, R98, R107, R108, R117, R118, R127, R128, R137, R138, R147, R148: 22; 0402-TIGHT
S1, S2, S3, S4, S5, S6, S7, S8, S9, S10, S11, S12, S13, S14, S15: Reset; TACTILE_SWITCH_SMD_4.6X2.8MM
U1, U4, U6, U8, U10, U12, U14, U16, U18, U20, U22, U24, U26, U28, U30: 3.3V; SOT23-5
U2, U3, U5, U7, U9, U11, U13, U15, U17, U19, U21, U23, U25, U27, U29: ATmega32U4; QFN-44-NOPAD_1:1
U$1, U$124, U$187, U$250, U$313, U$376, U$439, U$502, U$565, U$628, U$691, U$754, U$817, U$880, U$943: VCC1
U$2, U$38, U$70, U$101, U$133, U$164, U$196, U$227, U$259, U$290, U$322, U$353, U$385, U$416, U$448, U$479, U$511, U$542, U$574, U$605, U$637, U$668, U$700, U$731, U$763, U$794, U$826, U$857, U$889, U$920: 156
U$3, U$20, U$127, U$190, U$253, U$316, U$379, U$442, U$505, U$568, U$631, U$694, U$757, U$820, U$883: OSHW-LOGOMINI; OSHW-LOGO-MINI
U$4, U$48, U$71, U$103, U$134, U$166, U$197, U$229, U$260, U$292, U$323, U$355, U$386, U$418, U$449, U$481, U$512, U$544, U$575, U$607, U$638, U$670, U$701, U$733, U$764, U$796, U$827, U$859, U$890, U$922: 164
U$5, U$57, U$72, U$112, U$135, U$175, U$198, U$238, U$261, U$301, U$324, U$364, U$387, U$427, U$450, U$490, U$513, U$553, U$576, U$616, U$639, U$679, U$702, U$742, U$765, U$805, U$828, U$868, U$891, U$931: 218
U$6, U$56, U$73, U$111, U$136, U$174, U$199, U$237, U$262, U$300, U$325, U$363, U$388, U$426, U$451, U$489, U$514, U$552, U$577, U$615, U$640, U$678, U$703, U$741, U$766, U$804, U$829, U$867, U$892, U$930: 317
U$7, U$54, U$74, U$109, U$137, U$172, U$200, U$235, U$263, U$298, U$326, U$361, U$389, U$424, U$452, U$487, U$515, U$550, U$578, U$613, U$641, U$676, U$704, U$739, U$767, U$802, U$830, U$865, U$893, U$928: 515
U$8, U$53, U$75, U$108, U$138, U$171, U$201, U$234, U$264, U$297, U$327, U$360, U$390, U$423, U$453, U$486, U$516, U$549, U$579, U$612, U$642, U$675, U$705, U$738, U$768, U$801, U$831, U$864, U$894, U$927: 614
U$9, U$52, U$76, U$107, U$139, U$170, U$202, U$233, U$265, U$296, U$328, U$359, U$391, U$422, U$454, U$485, U$517, U$548, U$580, U$611, U$643, U$674, U$706, U$737, U$769, U$800, U$832, U$863, U$895, U$926: 713
U$10, U$51, U$77, U$106, U$140, U$169, U$203, U$232, U$266, U$295, U$329, U$358, U$392, U$421, U$455, U$484, U$518, U$547, U$581, U$610, U$644, U$673, U$707, U$736, U$770, U$799, U$833, U$862, U$896, U$925: 812
U$11, U$22, U$32, U$58, U$84, U$91, U$113, U$116, U$147, U$154, U$176, U$179, U$210, U$217, U$239, U$242, U$273, U$280, U$302, U$305, U$336, U$343, U$365, U$368, U$399, U$406, U$428, U$431, U$462, U$469, U$491, U$494, U$525, U$532, U$554, U$557, U$588, U$595, U$617, U$620, U$651, U$658, U$680, U$683, U$714, U$721, U$743, U$746, U$777, U$784, U$806, U$809, U$840, U$847, U$869, U$872, U$903, U$910, U$932, U$935: GND4
U$12, U$46, U$88, U$95, U$151, U$158, U$214, U$221, U$277, U$284, U$340, U$347, U$403, U$410, U$466, U$473, U$529, U$536, U$592, U$599, U$655, U$662, U$718, U$725, U$781, U$788, U$844, U$851, U$907, U$914: RAW5
U$13, U$33, U$55, U$110, U$128, U$173, U$191, U$236, U$254, U$299, U$317, U$362, U$380, U$425, U$443, U$488, U$506, U$551, U$569, U$614, U$632, U$677, U$695, U$740, U$758, U$803, U$821, U$866, U$884, U$929: 45
U$14, U$89, U$152, U$215, U$278, U$341, U$404, U$467, U$530, U$593, U$656, U$719, U$782, U$845, U$908: T8
U$15, U$64, U$65, U$123, U$125, U$126, U$186, U$188, U$189, U$249, U$251, U$252, U$312, U$314, U$315, U$375, U$377, U$378, U$438, U$440, U$441, U$501, U$503, U$504, U$564, U$566, U$567, U$627, U$629, U$630, U$690, U$692, U$693, U$753, U$755, U$756, U$816, U$818, U$819, U$879, U$881, U$882, U$942, U$944, U$945: 5V1
U$16, U$50, U$78, U$105, U$141, U$168, U$204, U$231, U$267, U$294, U$330, U$357, U$393, U$420, U$456, U$483, U$519, U$546, U$582, U$609, U$645, U$672, U$708, U$735, U$771, U$798, U$834, U$861, U$897, U$924: 911
U$17, U$37, U$79, U$100, U$142, U$163, U$205, U$226, U$268, U$289, U$331, U$352, U$394, U$415, U$457, U$478, U$520, U$541, U$583, U$604, U$646, U$667, U$709, U$730, U$772, U$793, U$835, U$856, U$898, U$919: A07
U$18, U$60, U$66, U$115, U$129, U$178, U$192, U$241, U$255, U$304, U$318, U$367, U$381, U$430, U$444, U$493, U$507, U$556, U$570, U$619, U$633, U$682, U$696, U$745, U$759, U$808, U$822, U$871, U$885, U$934: TX2
U$19, U$36, U$80, U$99, U$143, U$162, U$206, U$225, U$269, U$288, U$332, U$351, U$395, U$414, U$458, U$477, U$521, U$540, U$584, U$603, U$647, U$666, U$710, U$729, U$773, U$792, U$836, U$855, U$899, U$918: A18
U$21, U$49, U$67, U$104, U$130, U$167, U$193, U$230, U$256, U$293, U$319, U$356, U$382, U$419, U$445, U$482, U$508, U$545, U$571, U$608, U$634, U$671, U$697, U$734, U$760, U$797, U$823, U$860, U$886, U$923: 104
U$23, U$68, U$131, U$194, U$257, U$320, U$383, U$446, U$509, U$572, U$635, U$698, U$761, U$824, U$887: MICRO1
U$24, U$69, U$132, U$195, U$258, U$321, U$384, U$447, U$510, U$573, U$636, U$699, U$762, U$825, U$888: PRO0
U$25, U$31, U$41, U$85, U$90, U$96, U$148, U$153, U$159, U$211, U$216, U$222, U$274, U$279, U$285, U$337, U$342, U$348, U$400, U$405, U$411, U$463, U$468, U$474, U$526, U$531, U$537, U$589, U$594, U$600, U$652, U$657, U$663, U$715, U$720, U$726, U$778, U$783, U$789, U$841, U$846, U$852, U$904, U$909, U$915: RST3
U$26, U$35, U$81, U$98, U$144, U$161, U$207, U$224, U$270, U$287, U$333, U$350, U$396, U$413, U$459, U$476, U$522, U$539, U$585, U$602, U$648, U$665, U$711, U$728, U$774, U$791, U$837, U$854, U$900, U$917: A29
U$27, U$34, U$82, U$97, U$145, U$160, U$208, U$223, U$271, U$286, U$334, U$349, U$397, U$412, U$460, U$475, U$523, U$538, U$586, U$601, U$649, U$664, U$712, U$727, U$775, U$790, U$838, U$853, U$901, U$916: A310
U$28, U$59, U$83, U$114, U$146, U$177, U$209, U$240, U$272, U$303, U$335, U$366, U$398, U$429, U$461, U$492, U$524, U$555, U$587, U$618, U$650, U$681, U$713, U$744, U$776, U$807, U$839, U$870, U$902, U$933: RX20
U$29, U$47, U$86, U$102, U$149, U$165, U$212, U$228, U$275, U$291, U$338, U$354, U$401, U$417, U$464, U$480, U$527, U$543, U$590, U$606, U$653, U$669, U$716, U$732, U$779, U$795, U$842, U$858, U$905, U$921: 145
U$30, U$87, U$150, U$213, U$276, U$339, U$402, U$465, U$528, U$591, U$654, U$717, U$780, U$843, U$906: R9
U$39, U$117, U$180, U$243, U$306, U$369, U$432, U$495, U$558, U$621, U$684, U$747, U$810, U$873, U$936: 3V39
U$40, U$92, U$155, U$218, U$281, U$344, U$407, U$470, U$533, U$596, U$659, U$722, U$785, U$848, U$911: C5
U$42, U$118, U$181, U$244, U$307, U$370, U$433, U$496, U$559, U$622, U$685, U$748, U$811, U$874, U$937: G1
U$43, U$93, U$156, U$219, U$282, U$345, U$408, U$471, U$534, U$597, U$660, U$723, U$786, U$849, U$912: MICRO4
U$44, U$119, U$182, U$245, U$308, U$371, U$434, U$497, U$560, U$623, U$686, U$749, U$812, U$875, U$938: V0
U$45, U$94, U$157, U$220, U$283, U$346, U$409, U$472, U$535, U$598, U$661, U$724, U$787, U$850, U$913: PRO3
U$61, U$120, U$183, U$246, U$309, U$372, U$435, U$498, U$561, U$624, U$687, U$750, U$813, U$876, U$939: D#3
U$62, U$121, U$184, U$247, U$310, U$373, U$436, U$499, U$562, U$625, U$688, U$751, U$814, U$877, U$940: D#4
U$63, U$122, U$185, U$248, U$311, U$374, U$437, U$500, U$563, U$626, U$689, U$752, U$815, U$878, U$941: PWR0
Y1, Y2, Y3, Y4, Y5, Y6, Y7, Y8, Y9, Y10, Y11, Y12, Y13, Y14, Y15: 32MHz; CRYSTAL-SMD-2.0X1.6MM

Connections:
3.3V: C8.2, J2.2, JP4.1, R5.2, R7.2, R11.2, U1.5
3.3V1: C18.2, J1.2, JP7.1, R10.2, R19.2, R20.2, U4.5
3.3V2: C27.2, J9.2, JP11.1, R21.2, R29.2, R30.2, U6.5
3.3V3: C36.2, J13.2, JP16.1, R31.2, R39.2, R40.2, U8.5
3.3V4: C45.2, J17.2, JP20.1, R41.2, R49.2, R50.2, U10.5
3.3V5: C54.2, J21.2, JP24.1, R51.2, R59.2, R60.2, U12.5
3.3V6: C63.2, J25.2, JP28.1, R61.2, R69.2, R70.2, U14.5
3.3V7: C72.2, J29.2, JP32.1, R71.2, R79.2, R80.2, U16.5
3.3V8: C81.2, J33.2, JP36.1, R81.2, R89.2, R90.2, U18.5
3.3V9: C90.2, J37.2, JP40.1, R91.2, R99.2, R100.2, U20.5
3.3V10: C99.2, J41.2, JP44.1, R101.2, R109.2, R110.2, U22.5
3.3V11: C108.2, J45.2, JP48.1, R111.2, R119.2, R120.2, U24.5
3.3V12: C117.2, J49.2, JP52.1, R121.2, R129.2, R130.2, U26.5
3.3V13: C126.2, J53.2, JP56.1, R131.2, R139.2, R140.2, U28.5
3.3V14: C135.2, J57.2, JP60.1, R141.2, R149.2, R150.2, U30.5
A0: J4.8, J4.8B, U3.36
A1: J4.7, J4.7B, U3.37
A2: J4.6, J4.6B, U3.38
A3: J4.5, J4.5B, U3.39
A4: J7.5, J7.5B, U2.39
A5: J7.6, J7.6B, U2.38
A6: J7.7, J7.7B, U2.37
A7: J7.8, J7.8B, U2.36
A8: J11.5, J11.5B, U5.39
A9: J11.6, J11.6B, U5.38
A10: J11.7, J11.7B, U5.37
A11: J11.8, J11.8B, U5.36
A12: J15.5, J15.5B, U7.39
A13: J15.6, J15.6B, U7.38
A14: J15.7, J15.7B, U7.37
A15: J15.8, J15.8B, U7.36
A16: J19.5, J19.5B, U9.39
A17: J19.6, J19.6B, U9.38
A18: J19.7, J19.7B, U9.37
A19: J19.8, J19.8B, U9.36
A20: J23.5, J23.5B, U11.39
A21: J23.6, J23.6B, U11.38
A22: J23.7, J23.7B, U11.37
A23: J23.8, J23.8B, U11.36
A24: J27.5, J27.5B, U13.39
A25: J27.6, J27.6B, U13.38
A26: J27.7, J27.7B, U13.37
A27: J27.8, J27.8B, U13.36
A28: J31.5, J31.5B, U15.39
A29: J31.6, J31.6B, U15.38
A30: J31.7, J31.7B, U15.37
A31: J31.8, J31.8B, U15.36
A32: J35.5, J35.5B, U17.39
A33: J35.6, J35.6B, U17.38
A34: J35.7, J35.7B, U17.37
A35: J35.8, J35.8B, U17.36
A36: J39.5, J39.5B, U19.39
A37: J39.6, J39.6B, U19.38
A38: J39.7, J39.7B, U19.37
A39: J39.8, J39.8B, U19.36
A40: J43.5, J43.5B, U21.39
A41: J43.6, J43.6B, U21.38
A42: J43.7, J43.7B, U21.37
A43: J43.8, J43.8B, U21.36
A44: J47.5, J47.5B, U23.39
A45: J47.6, J47.6B, U23.38
A46: J47.7, J47.7B, U23.37
A47: J47.8, J47.8B, U23.36
A48: J51.5, J51.5B, U25.39
A49: J51.6, J51.6B, U25.38
A50: J51.7, J51.7B, U25.37
A51: J51.8, J51.8B, U25.36
A52: J55.5, J55.5B, U27.39
A53: J55.6, J55.6B, U27.38
A54: J55.7, J55.7B, U27.37
A55: J55.8, J55.8B, U27.36
A56: J59.5, J59.5B, U29.39
A57: J59.6, J59.6B, U29.38
A58: J59.7, J59.7B, U29.37
A59: J59.8, J59.8B, U29.36
AREF: C1.2, U3.42
AREF1: C12.2, U2.42
AREF2: C21.2, U5.42
AREF3: C30.2, U7.42
AREF4: C39.2, U9.42
AREF5: C48.2, U11.42
AREF6: C57.2, U13.42
AREF7: C66.2, U15.42
AREF8: C75.2, U17.42
AREF9: C84.2, U19.42
AREF10: C93.2, U21.42
AREF11: C102.2, U23.42
AREF12: C111.2, U25.42
AREF13: C120.2, U27.42
AREF14: C129.2, U29.42
D1: J6.1, J6.1B, U2.29
D2: J6.2, J6.2B, U2.28
D2/SDA: J2.3, J3.8, J3.8B, R5.1, U3.19
D2/SDA1: J1.3, J6.8, J6.8B, R19.1, U2.19
D2/SDA2: J9.3, J10.8, J10.8B, R29.1, U5.19
D2/SDA3: J13.3, J14.8, J14.8B, R39.1, U7.19
D2/SDA4: J17.3, J18.8, J18.8B, R49.1, U9.19
D2/SDA5: J21.3, J22.8, J22.8B, R59.1, U11.19
D2/SDA6: J25.3, J26.8, J26.8B, R69.1, U13.19
D2/SDA7: J29.3, J30.8, J30.8B, R79.1, U15.19
D2/SDA8: J33.3, J34.8, J34.8B, R89.1, U17.19
D2/SDA9: J37.3, J38.8, J38.8B, R99.1, U19.19
D2/SDA10: J41.3, J42.8, J42.8B, R109.1, U21.19
D2/SDA11: J45.3, J46.8, J46.8B, R119.1, U23.19
D2/SDA12: J49.3, J50.8, J50.8B, R129.1, U25.19
D2/SDA13: J53.3, J54.8, J54.8B, R139.1, U27.19
D2/SDA14: J57.3, J58.8, J58.8B, R149.1, U29.19
D3: J6.6, J6.6B, U2.25
D3/SCL: J2.4, J3.7, J3.7B, R7.1, U3.18
D3/SCL1: J1.4, J6.7, J6.7B, R20.1, U2.18
D3/SCL2: J9.4, J10.7, J10.7B, R30.1, U5.18
D3/SCL3: J13.4, J14.7, J14.7B, R40.1, U7.18
D3/SCL4: J17.4, J18.7, J18.7B, R50.1, U9.18
D3/SCL5: J21.4, J22.7, J22.7B, R60.1, U11.18
D3/SCL6: J25.4, J26.7, J26.7B, R70.1, U13.18
D3/SCL7: J29.4, J30.7, J30.7B, R80.1, U15.18
D3/SCL8: J33.4, J34.7, J34.7B, R90.1, U17.18
D3/SCL9: J37.4, J38.7, J38.7B, R100.1, U19.18
D3/SCL10: J41.4, J42.7, J42.7B, R110.1, U21.18
D3/SCL11: J45.4, J46.7, J46.7B, R120.1, U23.18
D3/SCL12: J49.4, J50.7, J50.7B, R130.1, U25.18
D3/SCL13: J53.4, J54.7, J54.7B, R140.1, U27.18
D3/SCL14: J57.4, J58.7, J58.7B, R150.1, U29.18
D4: J3.6, J3.6B, U3.25
D5: J3.5, J3.5B, U3.31
D6: J3.4, J3.4B, U3.27
D7: J3.3, J3.3B, U3.1
D8: J3.2, J3.2B, U3.28
D9: J3.1, J3.1B, U3.29
D10: J4.12, J4.12B, U3.30
D11: J6.5, J6.5B, U2.31
D12: J6.4, J6.4B, U2.27
D13: J6.3, J6.3B, U2.1
D14: J7.12, J7.12B, U2.30
D15: J10.1, J10.1B, U5.29
D16: J10.2, J10.2B, U5.28
D17: J10.6, J10.6B, U5.25
D18: J10.5, J10.5B, U5.31
D19: J10.4, J10.4B, U5.27
D20: J10.3, J10.3B, U5.1
D21: J11.12, J11.12B, U5.30
D22: J14.1, J14.1B, U7.29
D23: J14.2, J14.2B, U7.28
D24: J14.6, J14.6B, U7.25
D25: J14.5, J14.5B, U7.31
D26: J14.4, J14.4B, U7.27
D27: J14.3, J14.3B, U7.1
D28: J15.12, J15.12B, U7.30
D29: J18.1, J18.1B, U9.29
D30: J18.2, J18.2B, U9.28
D31: J18.6, J18.6B, U9.25
D32: J18.5, J18.5B, U9.31
D33: J18.4, J18.4B, U9.27
D34: J18.3, J18.3B, U9.1
D35: J19.12, J19.12B, U9.30
D36: J22.1, J22.1B, U11.29
D37: J22.2, J22.2B, U11.28
D38: J22.6, J22.6B, U11.25
D39: J22.5, J22.5B, U11.31
D40: J22.4, J22.4B, U11.27
D41: J22.3, J22.3B, U11.1
D42: J23.12, J23.12B, U11.30
D43: J26.1, J26.1B, U13.29
D44: J26.2, J26.2B, U13.28
D45: J26.6, J26.6B, U13.25
D46: J26.5, J26.5B, U13.31
D47: J26.4, J26.4B, U13.27
D48: J26.3, J26.3B, U13.1
D49: J27.12, J27.12B, U13.30
D50: J30.1, J30.1B, U15.29
D51: J30.2, J30.2B, U15.28
D52: J30.6, J30.6B, U15.25
D53: J30.5, J30.5B, U15.31
D54: J30.4, J30.4B, U15.27
D55: J30.3, J30.3B, U15.1
D56: J31.12, J31.12B, U15.30
D57: J34.1, J34.1B, U17.29
D58: J34.2, J34.2B, U17.28
D59: J34.6, J34.6B, U17.25
D60: J34.5, J34.5B, U17.31
D61: J34.4, J34.4B, U17.27
D62: J34.3, J34.3B, U17.1
D63: J35.12, J35.12B, U17.30
D64: J38.1, J38.1B, U19.29
D65: J38.2, J38.2B, U19.28
D66: J38.6, J38.6B, U19.25
D67: J38.5, J38.5B, U19.31
D68: J38.4, J38.4B, U19.27
D69: J38.3, J38.3B, U19.1
D70: J39.12, J39.12B, U19.30
D71: J42.1, J42.1B, U21.29
D72: J42.2, J42.2B, U21.28
D73: J42.6, J42.6B, U21.25
D74: J42.5, J42.5B, U21.31
D75: J42.4, J42.4B, U21.27
D76: J42.3, J42.3B, U21.1
D77: J43.12, J43.12B, U21.30
D78: J46.1, J46.1B, U23.29
D79: J46.2, J46.2B, U23.28
D80: J46.6, J46.6B, U23.25
D81: J46.5, J46.5B, U23.31
D82: J46.4, J46.4B, U23.27
D83: J46.3, J46.3B, U23.1
D84: J47.12, J47.12B, U23.30
D85: J50.1, J50.1B, U25.29
D86: J50.2, J50.2B, U25.28
D87: J50.6, J50.6B, U25.25
D88: J50.5, J50.5B, U25.31
D89: J50.4, J50.4B, U25.27
D90: J50.3, J50.3B, U25.1
D91: J51.12, J51.12B, U25.30
D92: J54.1, J54.1B, U27.29
D93: J54.2, J54.2B, U27.28
D94: J54.6, J54.6B, U27.25
D95: J54.5, J54.5B, U27.31
D96: J54.4, J54.4B, U27.27
D97: J54.3, J54.3B, U27.1
D98: J55.12, J55.12B, U27.30
D99: J58.1, J58.1B, U29.29
D100: J58.2, J58.2B, U29.28
D101: J58.6, J58.6B, U29.25
D102: J58.5, J58.5B, U29.31
D103: J58.4, J58.4B, U29.27
D104: J58.3, J58.3B, U29.1
D105: J59.12, J59.12B, U29.30
D+: R9.2, U3.4
D+1: R18.2, U2.4
D+2: R28.2, U5.4
D+3: R38.2, U7.4
D+4: R48.2, U9.4
D+5: R58.2, U11.4
D+6: R68.2, U13.4
D+7: R78.2, U15.4
D+8: R88.2, U17.4
D+9: R98.2, U19.4
D+10: R108.2, U21.4
D+11: R118.2, U23.4
D+12: R128.2, U25.4
D+13: R138.2, U27.4
D+14: R148.2, U29.4
D-: R8.2, U3.3
D-1: R17.2, U2.3
D-2: R27.2, U5.3
D-3: R37.2, U7.3
D-4: R47.2, U9.3
D-5: R57.2, U11.3
D-6: R67.2, U13.3
D-7: R77.2, U15.3
D-8: R87.2, U17.3
D-9: R97.2, U19.3
D-10: R107.2, U21.3
D-11: R117.2, U23.3
D-12: R127.2, U25.3
D-13: R137.2, U27.3
D-14: R147.2, U29.3
D-_HV: J5.A7, J5.B7, JP14.D-, R8.1
D-_HV1: J8.A7, J8.B7, JP6.D-, R17.1
D-_HV2: J12.A7, J12.B7, JP10.D-, R27.1
D-_HV3: J16.A7, J16.B7, JP15.D-, R37.1
D-_HV4: J20.A7, J20.B7, JP19.D-, R47.1
D-_HV5: J24.A7, J24.B7, JP23.D-, R57.1
D-_HV6: J28.A7, J28.B7, JP27.D-, R67.1
D-_HV7: J32.A7, J32.B7, JP31.D-, R77.1
D-_HV8: J36.A7, J36.B7, JP35.D-, R87.1
D-_HV9: J40.A7, J40.B7, JP39.D-, R97.1
D-_HV10: J44.A7, J44.B7, JP43.D-, R107.1
D-_HV11: J48.A7, J48.B7, JP47.D-, R117.1
D-_HV12: J52.A7, J52.B7, JP51.D-, R127.1
D-_HV13: J56.A7, J56.B7, JP55.D-, R137.1
D-_HV14: J60.A7, J60.B7, JP59.D-, R147.1
DP_HV: J5.A6, J5.B6, JP14.D+, R9.1
DP_HV1: J8.A6, J8.B6, JP6.D+, R18.1
DP_HV2: J12.A6, J12.B6, JP10.D+, R28.1
DP_HV3: J16.A6, J16.B6, JP15.D+, R38.1
DP_HV4: J20.A6, J20.B6, JP19.D+, R48.1
DP_HV5: J24.A6, J24.B6, JP23.D+, R58.1
DP_HV6: J28.A6, J28.B6, JP27.D+, R68.1
DP_HV7: J32.A6, J32.B6, JP31.D+, R78.1
DP_HV8: J36.A6, J36.B6, JP35.D+, R88.1
DP_HV9: J40.A6, J40.B6, JP39.D+, R98.1
DP_HV10: J44.A6, J44.B6, JP43.D+, R108.1
DP_HV11: J48.A6, J48.B6, JP47.D+, R118.1
DP_HV12: J52.A6, J52.B6, JP51.D+, R128.1
DP_HV13: J56.A6, J56.B6, JP55.D+, R138.1
DP_HV14: J60.A6, J60.B6, JP59.D+, R148.1
GND: C1.1, C2.2, C3.1, C4.2, C5.1, C6.1, C7.1, C8.1, C10.1, J2.1, J3.9, J3.9B, J3.10, J3.10B, J4.2, J4.2B, J5.GND, J5.GND2, JP14.GND, LED1.C, R1.1, R3.1, S1.1, S1.2, U1.2, U3.5, U3.15, U3.23, U3.33, U3.35, U3.43
GND1: C9.1, C11.1, C12.1, C13.2, C14.2, C15.1, C16.1, C17.1, C18.1, J1.1, J6.9, J6.9B, J6.10, J6.10B, J7.2, J7.2B, J8.GND, J8.GND2, JP6.GND, LED2.C, R15.1, R16.1, S2.1, S2.2, U2.5, U2.15, U2.23, U2.33, U2.35, U2.43, U4.2
GND2: C19.1, C20.1, C21.1, C22.2, C23.2, C24.1, C25.1, C26.1, C27.1, J9.1, J10.9, J10.9B, J10.10, J10.10B, J11.2, J11.2B, J12.GND, J12.GND2, JP10.GND, LED3.C, R25.1, R26.1, S3.1, S3.2, U5.5, U5.15, U5.23, U5.33, U5.35, U5.43, U6.2
GND3: C28.1, C29.1, C30.1, C31.2, C32.2, C33.1, C34.1, C35.1, C36.1, J13.1, J14.9, J14.9B, J14.10, J14.10B, J15.2, J15.2B, J16.GND, J16.GND2, JP15.GND, LED4.C, R35.1, R36.1, S4.1, S4.2, U7.5, U7.15, U7.23, U7.33, U7.35, U7.43, U8.2
GND4: C37.1, C38.1, C39.1, C40.2, C41.2, C42.1, C43.1, C44.1, C45.1, J17.1, J18.9, J18.9B, J18.10, J18.10B, J19.2, J19.2B, J20.GND, J20.GND2, JP19.GND, LED5.C, R45.1, R46.1, S5.1, S5.2, U9.5, U9.15, U9.23, U9.33, U9.35, U9.43, U10.2
GND5: C46.1, C47.1, C48.1, C49.2, C50.2, C51.1, C52.1, C53.1, C54.1, J21.1, J22.9, J22.9B, J22.10, J22.10B, J23.2, J23.2B, J24.GND, J24.GND2, JP23.GND, LED6.C, R55.1, R56.1, S6.1, S6.2, U11.5, U11.15, U11.23, U11.33, U11.35, U11.43, U12.2
GND6: C55.1, C56.1, C57.1, C58.2, C59.2, C60.1, C61.1, C62.1, C63.1, J25.1, J26.9, J26.9B, J26.10, J26.10B, J27.2, J27.2B, J28.GND, J28.GND2, JP27.GND, LED7.C, R65.1, R66.1, S7.1, S7.2, U13.5, U13.15, U13.23, U13.33, U13.35, U13.43, U14.2
GND7: C64.1, C65.1, C66.1, C67.2, C68.2, C69.1, C70.1, C71.1, C72.1, J29.1, J30.9, J30.9B, J30.10, J30.10B, J31.2, J31.2B, J32.GND, J32.GND2, JP31.GND, LED8.C, R75.1, R76.1, S8.1, S8.2, U15.5, U15.15, U15.23, U15.33, U15.35, U15.43, U16.2
GND8: C73.1, C74.1, C75.1, C76.2, C77.2, C78.1, C79.1, C80.1, C81.1, J33.1, J34.9, J34.9B, J34.10, J34.10B, J35.2, J35.2B, J36.GND, J36.GND2, JP35.GND, LED9.C, R85.1, R86.1, S9.1, S9.2, U17.5, U17.15, U17.23, U17.33, U17.35, U17.43, U18.2
GND9: C82.1, C83.1, C84.1, C85.2, C86.2, C87.1, C88.1, C89.1, C90.1, J37.1, J38.9, J38.9B, J38.10, J38.10B, J39.2, J39.2B, J40.GND, J40.GND2, JP39.GND, LED10.C, R95.1, R96.1, S10.1, S10.2, U19.5, U19.15, U19.23, U19.33, U19.35, U19.43, U20.2
GND10: C91.1, C92.1, C93.1, C94.2, C95.2, C96.1, C97.1, C98.1, C99.1, J41.1, J42.9, J42.9B, J42.10, J42.10B, J43.2, J43.2B, J44.GND, J44.GND2, JP43.GND, LED11.C, R105.1, R106.1, S11.1, S11.2, U21.5, U21.15, U21.23, U21.33, U21.35, U21.43, U22.2
GND11: C100.1, C101.1, C102.1, C103.2, C104.2, C105.1, C106.1, C107.1, C108.1, J45.1, J46.9, J46.9B, J46.10, J46.10B, J47.2, J47.2B, J48.GND, J48.GND2, JP47.GND, LED12.C, R115.1, R116.1, S12.1, S12.2, U23.5, U23.15, U23.23, U23.33, U23.35, U23.43, U24.2
GND12: C109.1, C110.1, C111.1, C112.2, C113.2, C114.1, C115.1, C116.1, C117.1, J49.1, J50.9, J50.9B, J50.10, J50.10B, J51.2, J51.2B, J52.GND, J52.GND2, JP51.GND, LED13.C, R125.1, R126.1, S13.1, S13.2, U25.5, U25.15, U25.23, U25.33, U25.35, U25.43, U26.2
GND13: C118.1, C119.1, C120.1, C121.2, C122.2, C123.1, C124.1, C125.1, C126.1, J53.1, J54.9, J54.9B, J54.10, J54.10B, J55.2, J55.2B, J56.GND, J56.GND2, JP55.GND, LED14.C, R135.1, R136.1, S14.1, S14.2, U27.5, U27.15, U27.23, U27.33, U27.35, U27.43, U28.2
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

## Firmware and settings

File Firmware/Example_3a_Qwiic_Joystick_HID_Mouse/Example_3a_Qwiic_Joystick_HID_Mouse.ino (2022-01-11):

/******************************************************************************
  Example_3a_Qwiic_Joystick_HID_Mouse.ino
  Written by: Ho Yun "Bobby" Chan
  Date: January 13, 2020
  Development Environment Specifics:
    Arduino IDE 1.8.9

  Description:
    Based on the Jim's Pro Micro "HID Mouse" and Wes' Qwiic Joystick "basic reading"
    examples, this example moves your computer's mouse based on the joystick's
    position. Pressing down on the joystick's will enable a mouse's left click.
    The left click will relese as soon as you stop pressing down on the joystick.

  Libraries:
    Mouse.h (included with Arduino IDE)
    Wire.h (included with Arduino IDE)
    SparkFun_Qwiic_Joystick_Arduino_Library.h (included in the src folder) http://librarymanager/All#SparkFun_joystick

  License:
    This code is released under the MIT License (http://opensource.org/licenses/MIT)

  ******************************************************************************/

#include <Mouse.h>
#include <Wire.h>

#include "SparkFun_Qwiic_Joystick_Arduino_Library.h" //Click here to get the library: http://librarymanager/All#SparkFun_joystick
JOYSTICK joystick;                                   //Create instance of this object

int vertZero, horzZero;       // Stores the initial value of each axis, usually around 512
int vertValue, horzValue;     // Stores current analog output of each axis
const int sensitivity = 200;  // Higher sensitivity value = slower mouse, should be <= about 500
int mouseClickFlag = 0;

//int invertMouse = 1;        //Invert joystick based on orientation
int invertMouse = -1;         //Noninverted joystick based on orientation

//Debug mode, comment one of these lines out using a syntax
//for a single line comment ("//"):
#define DEBUG 0       //0 = HID only
//#define DEBUG 1     //1 = HID with serial output

void setup() {
#if DEBUG
  Serial.begin(9600);
  Serial.println("Example 3: HID Mouse w/ Qwiic Joystick");
#endif

  if (joystick.begin() == false)
  {
#if DEBUG
    Serial.println("Joystick does not appear to be connected. Please check wiring. Freezing...");
#endif
    while (1);
  }

  delay(1000);  // short delay to let outputs settle
  vertZero = joystick.getVertical();  // get the initial values
  horzZero = joystick.getHorizontal();  // Joystick should be in neutral position when reading these

  Mouse.begin(); //Init mouse emulation
}

void loop() {
#if DEBUG
  Serial.print("X: ");
  Serial.print(joystick.getHorizontal());

  Serial.print(" Y: ");
  Serial.print(joystick.getVertical());

  Serial.print(" Button: ");
  Serial.println(joystick.getButton());
#endif

  vertValue = joystick.getVertical() - vertZero; // read vertical offset
  horzValue = joystick.getHorizontal() - horzZero;  // read horizontal offset

  if (vertValue != 0)
    Mouse.move(0, (invertMouse * (vertValue / sensitivity)), 0); // move mouse on y axis
  if (horzValue != 0)
    Mouse.move((invertMouse * (horzValue / sensitivity)), 0, 0); // move mouse on x axis

  if ((joystick.getButton() == 0) && (!mouseClickFlag))  // if the joystick button is pressed
  {
    mouseClickFlag = 1;
    Mouse.press(MOUSE_LEFT);  // click the left button down
  }
  else if ((joystick.getButton()) && (mouseClickFlag)) // if the joystick button is not pressed
  {
    mouseClickFlag = 0;
    Mouse.release(MOUSE_LEFT);  // release the left button
  }

  //delay(200); //remove "//" on this line if you need a small delay
}

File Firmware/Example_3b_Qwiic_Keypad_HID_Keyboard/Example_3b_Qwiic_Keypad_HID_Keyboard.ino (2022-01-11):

/******************************************************************************
  Example_3b_Qwiic_Keypad_HID_Keyboard.ino
  Written by: Ho Yun "Bobby" Chan
  Date: February 6, 2020
  Development Environment Specifics:
    Arduino IDE 1.8.9

  Description:
    Based on the Jim's Pro Micro "HID Mouse" and Pete' Qwiic Keypad "read button"
    examples, this example outputs keyboard presses associated with the keypad.

  Libraries:
   Keyboard.h (included with Arduino IDE)
   Wire.h (included with Arduino IDE)
   SparkFun_Qwiic_Keypad_Arduino_Library.h (included in the src folder) http://librarymanager/All#SparkFun_keypad

  License:
    This code is released under the MIT License (http://opensource.org/licenses/MIT)

******************************************************************************/

#include <Keyboard.h>
#include <Wire.h>
#include "SparkFun_Qwiic_Keypad_Arduino_Library.h" //Click here to get the library: http://librarymanager/All#SparkFun_keypad
KEYPAD keypad1;                                    //Create instance of this object

void setup() {
  Serial.begin(9600);
  Serial.println("Qwiic KeyPad Example");

  if (keypad1.begin() == false)   // Note, using begin() like this will use default I2C address, 0x4B.
    // You can pass begin() a different address like so: keypad1.begin(Wire, 0x4A).
  {
    Serial.println("Keypad does not appear to be connected. Please check wiring. Freezing...");
    while (1);
  }
  Serial.print("Initialized. Firmware Version: ");
  Serial.println(keypad1.getVersion());
  Serial.println("Press a button: * to do a space. # to go to next line.");

  Keyboard.begin(); //Init keyboard emulation
}

void loop() {
  keypad1.updateFIFO();  // necessary for keypad to pull button from stack to readable register
  char button = keypad1.getButton();

  if (button == -1)
  {
    Serial.println("No keypad detected");
    delay(1000);
  }
  else if (button != 0)
  {
    if (button == '0') {//note that this is a keypad '0' not the button press itself
      Keyboard.write('0');
    }
    else if (button == '1') {
      Keyboard.write('1');
    }
    else if (button == '2') {
      Keyboard.write('2');
    }
    else if (button == '3') {
      Keyboard.write('3');
    }
    else if (button == '4') {
      Keyboard.write('4');
    }
    else if (button == '5') {
      Keyboard.write('5');
    }
    else if (button == '6') {
      Keyboard.write('6');
    }
    else if (button == '7') {
      Keyboard.write('7');
    }
    else if (button == '8') {
      Keyboard.write('8');
    }
    else if (button == '9') {
      Keyboard.write('9');
    }
    else if (button == '#') {
      Keyboard.write('#');
    }
    else if (button == '*') {
      Keyboard.write('*');
    }
  }

  //Do something else. Don't call your Keypad a ton otherwise you'll tie up the I2C bus
  delay(25); //25 is good, more is better
}

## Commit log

2013-05-28 Adding hardware files for revision v13
    Ready for prototype
    -Updated QFN Package on 32U4 to be 1:1
    -Updated Symbol of 32U4 in Schematic (switched MISO and SS placement)
    -Renamed SS net to D14 (from D17)
    -Re-Routed directly inward or outward from each leg on the IC
    -Added two small squares of tRestrict to keep the ground plane away from
    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
    [Pro_Micro.brd, Pro_Micro.sch]
2013-10-18 Updated v13 design files
    Updated usb connector, IC footprint and route job and moved from 0402 to
    0603.
    [Pro_Micro.brd, Pro_Micro.sch]
2015-06-19 Updating file names
    [SparkFun_Pro_Micro.brd, SparkFun_Pro_Micro.sch]
2015-06-19 Fixing 32u4 pin names
    [SparkFun_Pro_Micro.brd, SparkFun_Pro_Micro.sch]
2017-01-31 Adding graphical datasheet fixes from Michelle
    [ProMicro.csv]
2018-01-29 Wrong Pin in Graphical Datasheet
    Mark and a customer noticed that the TX_LED pin is mislabeled on the Graphical Datasheets for the Pro Micro [ [https://github.com/sparkfun/SF32u4_boards/blob/master/sparkfun/avr/variants/promicro/pins_arduino.h#L106](https://github.com/sparkfun/SF32u4_boards/blob/master/sparkfun/avr/variants/promicro/pins_arduino.h#L106) ]. It should be D30 instead of D24. Bobby verified by checking the schematic and testing the code.
2018-01-29 Update README.md
    -Add links to both versions of Pro Micro
    -Add link to hookup guide
    -Add links to Board Addon
    -Add link to graphical datasheets githip repo
2019-10-09 Proto finished. Add ignore.
    [SparkFun_Pro_Micro.brd, SparkFun_Pro_Micro.sch]
2019-10-09 Rev to USB C
    [SparkFun_Pro_Micro.brd, SparkFun_Pro_Micro.sch]
2019-10-10 Commit before ordering v20
    [SparkFun_Pro_Micro-Panel.GBL, SparkFun_Pro_Micro-Panel.GBO, SparkFun_Pro_Micro-Panel.GBS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]
2019-10-17 Adding production panel, pro micro FP test brd, and castellated test lbr.
    [Frank.GBL, Frank.GBO, Frank.GBP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]
2019-11-08 Updates to Pro Micro and Frank
    "Castellated" library '1x12CASTELLATED' and 'PRO_MICRO_C' footprints updated and 'PRO_MICRO_C' device updated.
    Pro Micro C got uniform drill/ring sizing + added plated holes to outside in place of drills
    Frank got 1U Keycap standard switch spacing and updated Pro Micro footprint.
    [Frank.GBL, Frank.GBO, Frank.GBP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]
2019-11-08 Red boards ordered
    Modify castellated 1x12 to larger diameter plated castellated holes. Panelize with route-out around castellated edges. Scoot Qwiic connector in to use that side of the board as the tab.
    [SparkFun_Pro_Micro-Panel.GBL, SparkFun_Pro_Micro-Panel.GBO, SparkFun_Pro_Micro-Panel.GBS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]
2019-11-19 Udpate xtal to 16MHz
    [SparkFun_Pro_Micro.brd, SparkFun_Pro_Micro.sch]
2019-12-11 Correct prodID on 22 ohm resistors.
    [SparkFun_Pro_Micro.brd, SparkFun_Pro_Micro.sch]
2019-12-20 Update SparkFun_Pro_Micro.brd
    - Adding board dimensions
    - Add additional distance between connectors to edge of board
    [SparkFun_Pro_Micro.brd]
2019-12-20 Update SparkFun_Pro_Micro.brd
    -Add distance USB C connector off edge of board
    [SparkFun_Pro_Micro.brd]
2020-01-07 fixing paste issue
    [SparkFun_Pro_Micro.brd, SparkFun_Pro_Micro.sch]
2020-01-07 Remove old test files
    [Frank.brd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]
2020-02-11 changing PROD_ID on series D+/D- resistor to proper PROD_ID
    [SparkFun_Pro_Micro.brd, SparkFun_Pro_Micro.sch]
2020-02-12 Update Pro Micro Examples
    - rename files to match the examples in the tutorial
    - adjust the output for the hardware UART in **Example_1_Blinkies_Hello.ino** file to distinguish betweeh the serial monitor
    - add `Keyboard.begin()` in `setup()` for **Example_2a_SimpleKeyboard_HID.ino** (this appears to work without initializing it but it was added to be consistent with Arduino's reference example)
    - add `Mouse.begin()` in `setup()` to **Example_2b_SimpleJoystickMouse_HID.ino** (this appears to work without initializing it but it was added to be consistent with Arduino's reference example)
    - include the ability to invert the mouse using the joystick depending on the orientation of the joystick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
    [Example_1_Blinkies_Hello.ino, Example_2a_SimpleKeyboard_HID.ino, Example_2b_SimpleJoystickMouse_HID.ino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]
2020-02-12 Update Old Pro Micro Examples
    - adjust the output for the hardware UART in **Blinkies.ino** file to distinguish betweeh the serial monitor
    - add `Keyboard.begin()` in `setup()` for **SimpleKeyboard_HID.ino** (this appears to work without initializing it but it was added to be consistent with Arduino's reference example)
    - add `Mouse.begin()` in `setup()` to **SimpleJoystickMouse_HID.ino** (this appears to work without initializing it but it was added to be consistent with Arduino's reference example)
    - include the ability to invert the mouse using the joystick depending on the orientation of the joystick
    -autoformat
2022-06-16 Add Older Version to Repo
    The product pages for the Pro Micro and the Qwiic Pro Micro USB-C versions currently point to this repo without the older Pro Micro's Hardware Files. Since we are still selling both, I am adding the 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
    [SparkFun_Pro_Micro-Panel.GBL, SparkFun_Pro_Micro-Panel.GBO, SparkFun_Pro_Micro-Panel.GBS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]

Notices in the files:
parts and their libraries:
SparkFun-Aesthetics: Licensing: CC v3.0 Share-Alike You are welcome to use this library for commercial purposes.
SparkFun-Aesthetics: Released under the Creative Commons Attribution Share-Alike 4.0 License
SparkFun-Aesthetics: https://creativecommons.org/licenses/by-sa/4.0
